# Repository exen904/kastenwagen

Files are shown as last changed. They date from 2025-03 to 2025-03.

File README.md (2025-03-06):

# Kastenwagen 1840 Chunky ISO RP2040

Kastenwagen 1840

Kastenwagen 1840 is a 40% keyboard with a mini-numpad and dedicated arrows.  The main alpha block is 13.75u long, allowing for more dedicated punctuation keys (or non-English letters) to be paired with common Minivan-like mod keys.

Kastenwagen 48 is a similar keyboard that replaces the mini-numpad with a small macro column.

For more information, join the [NoPunIn10Key Discord](https://discord.gg/sku2Y6w).

## RP2040 PCB Port
The PCB in this branch was ported for the use of a RP2040 Community Edition MCU, no Elite-C support! As the pinout of the Elite-C and the RP2040 community footprint is not exactly the same, one of the status LEDs was not working when using such an MCU. For that case, I switched the KiCad files to use a 0xCB Helios as base and changed some of the routing for the new pinout. All status LEDs are now confirmed working.

## Credit

* Keyboard Maintainer: [Alex Ronke](https://nopunin10did.com/), also known as [NoPunIn10Did](https://github.com/NoPunIn10Did)
* Hardware Supported: Kastenwagen 1840 (2021 June)
* Hardware Availability: Currently by request only

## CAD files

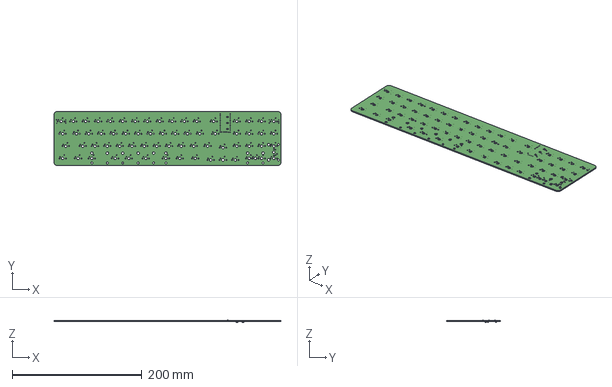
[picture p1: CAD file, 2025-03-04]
kastenwagen-1840-chunky/kastenwagen-1840-chunky.step
350.5 x 83.5 x 3.25 mm

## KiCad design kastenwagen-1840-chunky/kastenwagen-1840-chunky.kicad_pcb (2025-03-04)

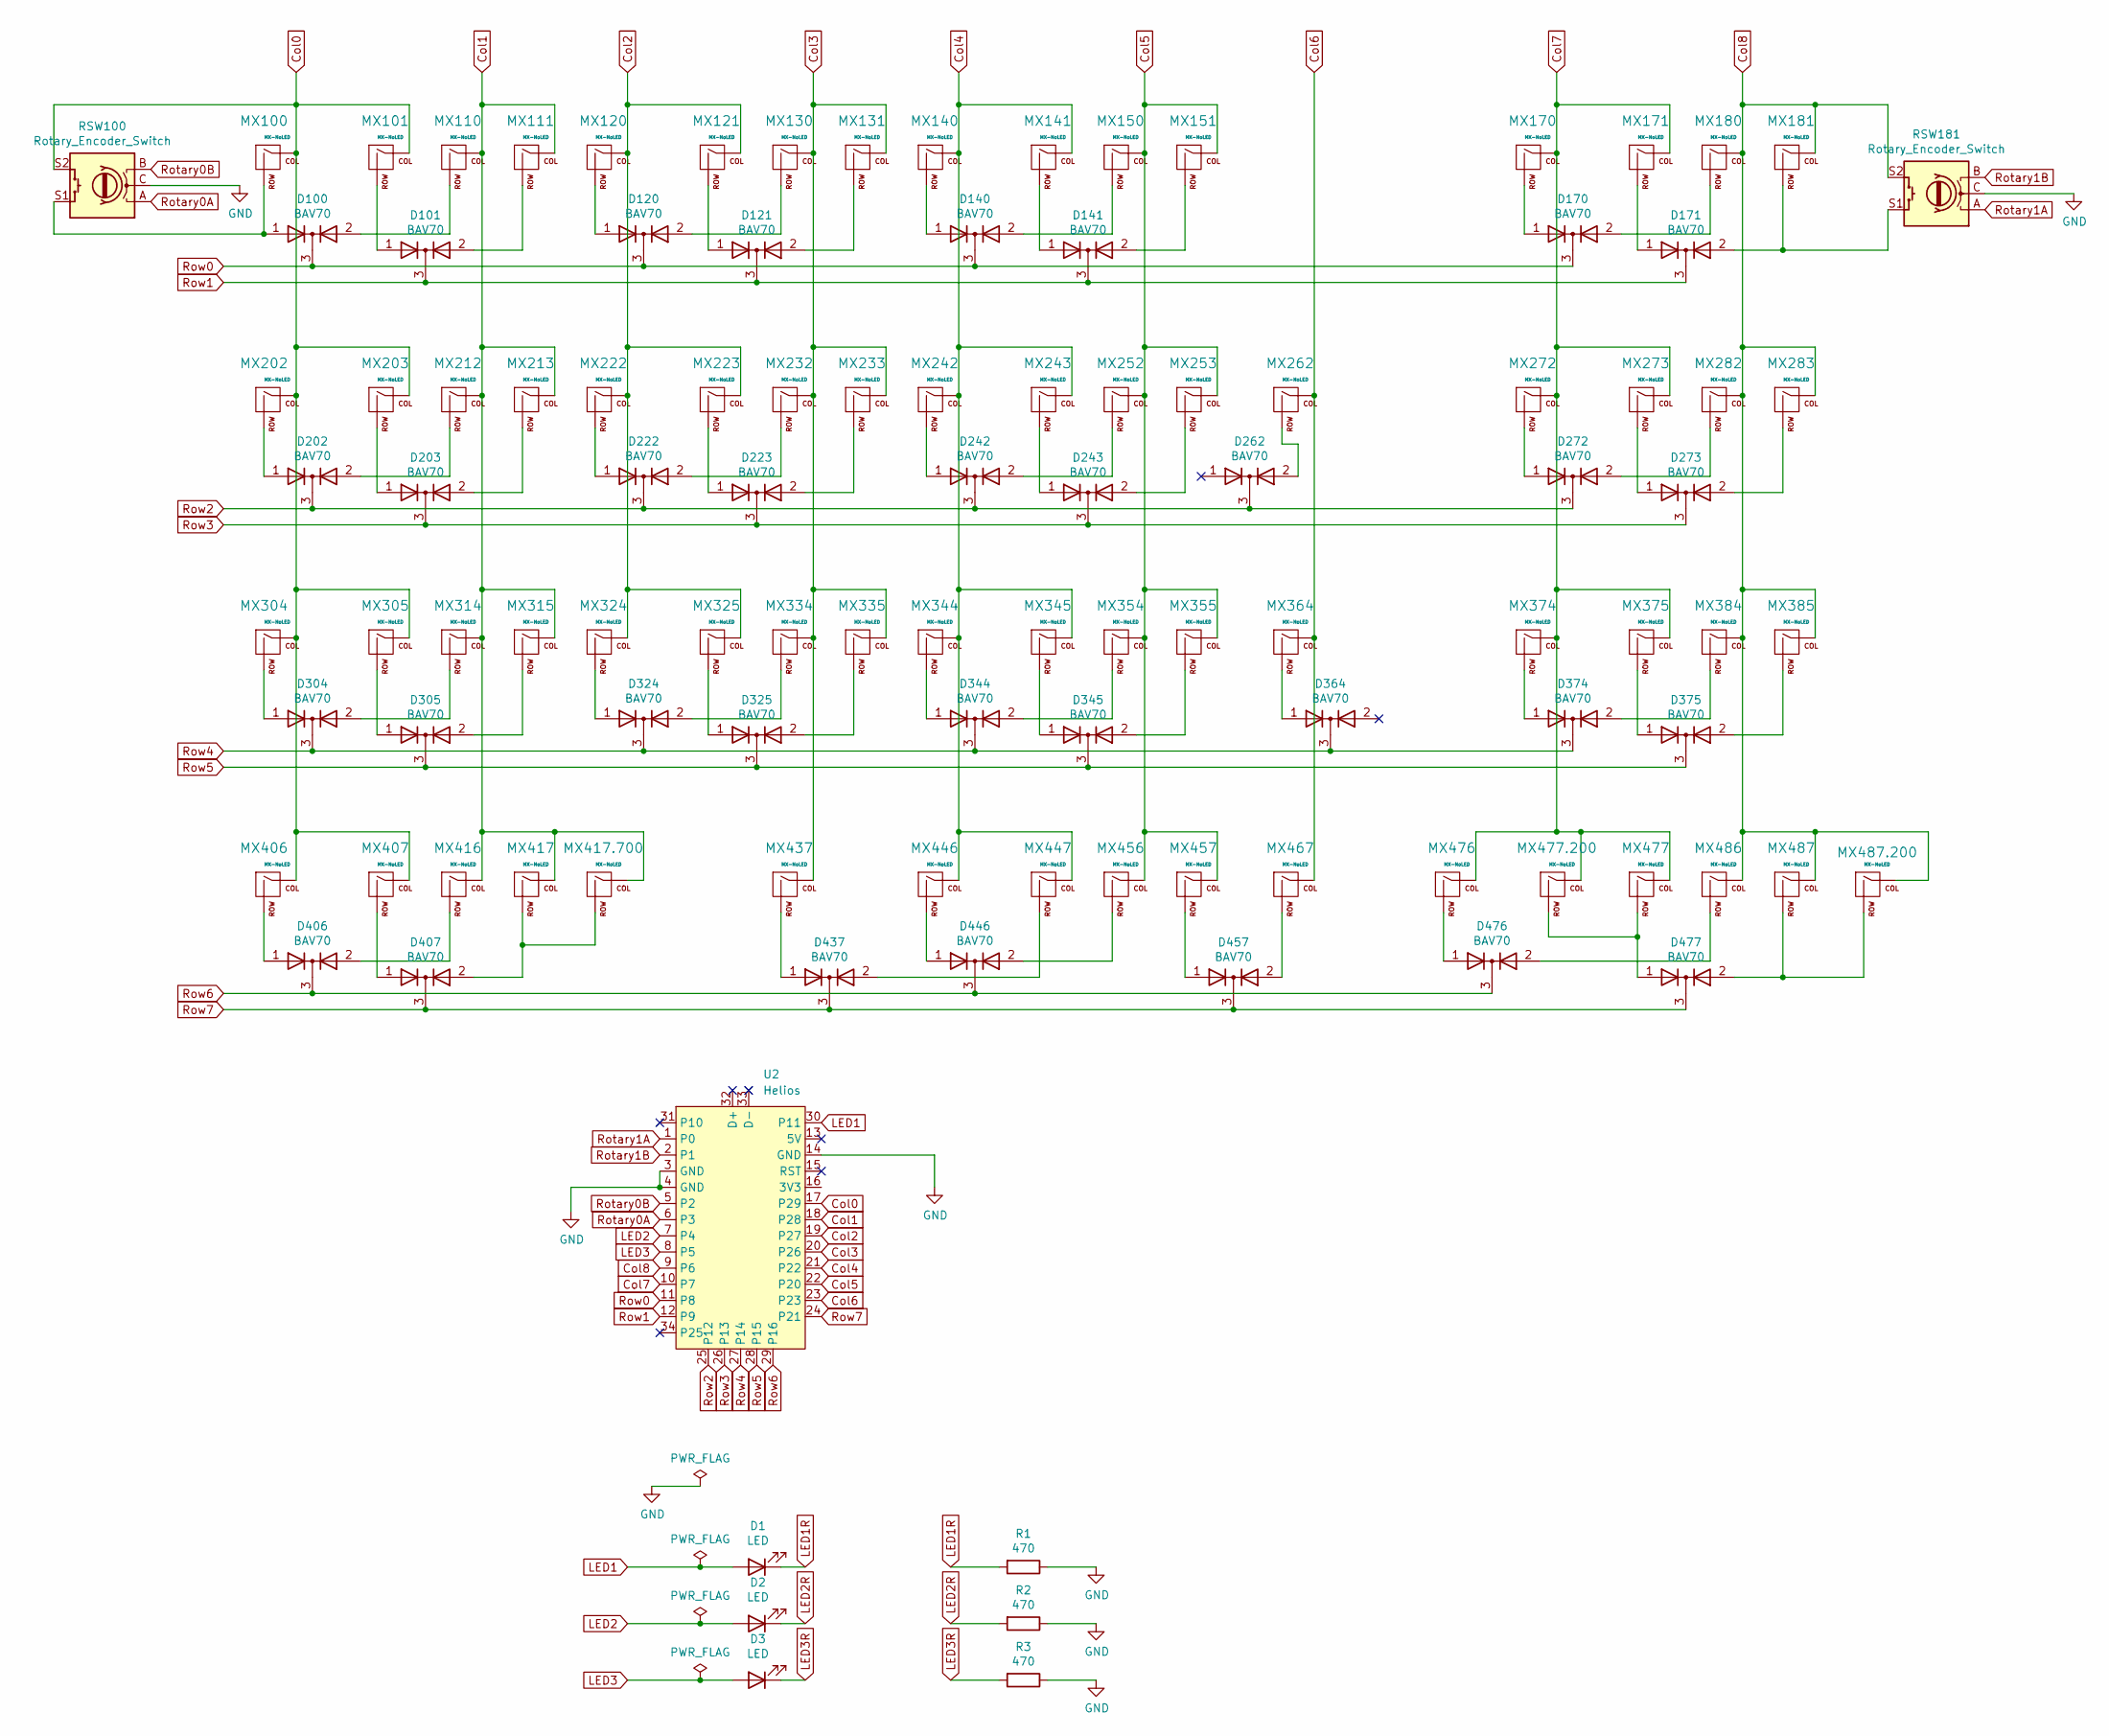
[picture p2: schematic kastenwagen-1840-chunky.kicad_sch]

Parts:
D1, D2, D3: LED; LED_1206_3216Metric_Pad1.42x1.75mm_HandSolder
D100, D101, D120, D121, D140, D141, D170, D171, D202, D203, D222, D223, D242, D243, D262, D272, D273, D304, D305, D324, D325, D344, D345, D364, D374, D375, D406, D407, D437, D446, D457, D476, D477: BAV70; SOT-23_Handsoldering
MX100, MX101, MX110, MX111, MX120, MX121, MX130, MX131, MX140, MX141, MX150, MX151, MX170, MX171, MX180, MX181, MX203, MX212, MX213, MX222, MX223, MX232, MX233, MX242, MX243, MX252, MX253, MX272, MX273, MX282, MX283, MX305, MX314, MX315, MX324, MX325, MX334, MX335, MX344, MX345, MX354, MX364, MX374, MX375, MX384, MX385, MX416, MX446, MX457, MX467, MX476, MX477, MX486, MX487: MX-NoLED; MXOnly-1U-NoLED
MX202, MX355, MX406, MX407, MX447, MX456: MX-NoLED; MXOnly-1.25U-NoLED
MX262: MX-NoLED; MXOnly-ISO-ROTATED-NoLED-NoStabs
MX304: MX-NoLED; MXOnly-1.75U-NoLED
MX417: MX-NoLED; MXOnly-2.75U-ReversedStabilizers-NoLED
MX417.700: MX-NoLED; MXOnly-7U-ReversedStabilizers-NoLED
MX437: MX-NoLED; MXOnly-2.25U-ReversedStabilizers-NoLED
MX477.200: MX-NoLED; MXOnly-2U-ReversedStabilizers-NoLED
MX487.200: MX-NoLED; MXOnly-2U-NoLED
R1, R2, R3: 470; R_0805
RSW100, RSW181: Rotary_Encoder_Switch; RotaryEncoder_EC11-no-legs
U2: Helios; Helios_AH_USBup

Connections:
Col0: MX100.1 (COL), MX101.1 (COL), MX202.1 (COL), MX203.1 (COL), MX304.1 (COL), MX305.1 (COL), MX406.1 (COL), MX407.1 (COL), RSW100.S2, U2.17 (P29)
Col1: MX110.1 (COL), MX111.1 (COL), MX212.1 (COL), MX213.1 (COL), MX314.1 (COL), MX315.1 (COL), MX416.1 (COL), MX417.1 (COL), MX417.700.1 (COL), U2.18 (P28)
Col2: MX120.1 (COL), MX121.1 (COL), MX222.1 (COL), MX223.1 (COL), MX324.1 (COL), MX325.1 (COL), U2.19 (P27)
Col3: MX130.1 (COL), MX131.1 (COL), MX232.1 (COL), MX233.1 (COL), MX334.1 (COL), MX335.1 (COL), MX437.1 (COL), U2.20 (P26)
Col4: MX140.1 (COL), MX141.1 (COL), MX242.1 (COL), MX243.1 (COL), MX344.1 (COL), MX345.1 (COL), MX446.1 (COL), MX447.1 (COL), U2.21 (P22)
Col5: MX150.1 (COL), MX151.1 (COL), MX252.1 (COL), MX253.1 (COL), MX354.1 (COL), MX355.1 (COL), MX456.1 (COL), MX457.1 (COL), U2.22 (P20)
Col6: MX262.1 (COL), MX364.1 (COL), MX467.1 (COL), U2.23
Col7: MX170.1 (COL), MX171.1 (COL), MX272.1 (COL), MX273.1 (COL), MX374.1 (COL), MX375.1 (COL), MX476.1 (COL), MX477.1 (COL), MX477.200.1 (COL), U2.10 (P7)
Col8: MX180.1 (COL), MX181.1 (COL), MX282.1 (COL), MX283.1 (COL), MX384.1 (COL), MX385.1 (COL), MX486.1 (COL), MX487.1 (COL), MX487.200.1 (COL), RSW181.S2, U2.9 (P6)
GND: R1.1, R2.1, R3.1, RSW100.C, RSW181.C, U2.3 (GND), U2.4 (GND), U2.14 (GND)
LED1: D1.2 (A), U2.30 (P11)
LED1R: D1.1 (K), R1.2
LED2: D2.2 (A), U2.7 (P4)
LED2R: D2.1 (K), R2.2
LED3: D3.2 (A), U2.8 (P5)
LED3R: D3.1 (K), R3.2
unnamed: D100.1 (A), MX100.2 (ROW), RSW100.S1
unnamed: D101.1 (A), MX101.2 (ROW)
unnamed: D100.2 (A), MX110.2 (ROW)
unnamed: D101.2 (A), MX111.2 (ROW)
unnamed: D120.1 (A), MX120.2 (ROW)
unnamed: D121.1 (A), MX121.2 (ROW)
unnamed: D120.2 (A), MX130.2 (ROW)
unnamed: D121.2 (A), MX131.2 (ROW)
unnamed: D140.1 (A), MX140.2 (ROW)
unnamed: D141.1 (A), MX141.2 (ROW)
unnamed: D140.2 (A), MX150.2 (ROW)
unnamed: D141.2 (A), MX151.2 (ROW)
unnamed: D170.1 (A), MX170.2 (ROW)
unnamed: D171.1 (A), MX171.2 (ROW)
unnamed: D170.2 (A), MX180.2 (ROW)
unnamed: D171.2 (A), MX181.2 (ROW), RSW181.S1
unnamed: D202.1 (A), MX202.2 (ROW)
unnamed: D203.1 (A), MX203.2 (ROW)
unnamed: D202.2 (A), MX212.2 (ROW)
unnamed: D203.2 (A), MX213.2 (ROW)
unnamed: D222.1 (A), MX222.2 (ROW)
unnamed: D223.1 (A), MX223.2 (ROW)
unnamed: D222.2 (A), MX232.2 (ROW)
unnamed: D223.2 (A), MX233.2 (ROW)
unnamed: D242.1 (A), MX242.2 (ROW)
unnamed: D243.1 (A), MX243.2 (ROW)
unnamed: D242.2 (A), MX252.2 (ROW)
unnamed: D243.2 (A), MX253.2 (ROW)
unnamed: D262.2 (A), MX262.2 (ROW)
unnamed: D272.1 (A), MX272.2 (ROW)
unnamed: D273.1 (A), MX273.2 (ROW)
unnamed: D272.2 (A), MX282.2 (ROW)
unnamed: D273.2 (A), MX283.2 (ROW)
unnamed: D304.1 (A), MX304.2 (ROW)
unnamed: D305.1 (A), MX305.2 (ROW)
unnamed: D304.2 (A), MX314.2 (ROW)
unnamed: D305.2 (A), MX315.2 (ROW)
unnamed: D324.1 (A), MX324.2 (ROW)
unnamed: D325.1 (A), MX325.2 (ROW)
unnamed: D324.2 (A), MX334.2 (ROW)
unnamed: D325.2 (A), MX335.2 (ROW)
unnamed: D344.1 (A), MX344.2 (ROW)
unnamed: D345.1 (A), MX345.2 (ROW)
unnamed: D344.2 (A), MX354.2 (ROW)
unnamed: D345.2 (A), MX355.2 (ROW)
unnamed: D364.1 (A), MX364.2 (ROW)
unnamed: D374.1 (A), MX374.2 (ROW)
unnamed: D375.1 (A), MX375.2 (ROW)
unnamed: D374.2 (A), MX384.2 (ROW)
unnamed: D375.2 (A), MX385.2 (ROW)
unnamed: D406.1 (A), MX406.2 (ROW)
unnamed: D407.1 (A), MX407.2 (ROW)
unnamed: D406.2 (A), MX416.2 (ROW)
unnamed: D407.2 (A), MX417.2 (ROW), MX417.700.2 (ROW)
unnamed: D437.1 (A), MX437.2 (ROW)
unnamed: D446.1 (A), MX446.2 (ROW)
unnamed: D437.2 (A), MX447.2 (ROW)
unnamed: D446.2 (A), MX456.2 (ROW)
unnamed: D457.1 (A), MX457.2 (ROW)
unnamed: D457.2 (A), MX467.2 (ROW)
unnamed: D476.1 (A), MX476.2 (ROW)
unnamed: D477.1 (A), MX477.2 (ROW), MX477.200.2 (ROW)
unnamed: D476.2 (A), MX486.2 (ROW)
unnamed: D477.2 (A), MX487.2 (ROW), MX487.200.2 (ROW)
Rotary0A: RSW100.A, U2.6 (P3)
Rotary0B: RSW100.B, U2.5 (P2)
Rotary1A: RSW181.A, U2.1 (P0)
Rotary1B: RSW181.B, U2.2 (P1)
Row0: D100.3 (K), D120.3 (K), D140.3 (K), D170.3 (K), U2.11 (P8)
Row1: D101.3 (K), D121.3 (K), D141.3 (K), D171.3 (K), U2.12 (P9)
Row2: D202.3 (K), D222.3 (K), D242.3 (K), D262.3 (K), D272.3 (K), U2.25 (P12)
Row3: D203.3 (K), D223.3 (K), D243.3 (K), D273.3 (K), U2.26 (P13)
Row4: D304.3 (K), D324.3 (K), D344.3 (K), D364.3 (K), D374.3 (K), U2.27 (P14)
Row5: D305.3 (K), D325.3 (K), D345.3 (K), D375.3 (K), U2.28 (P15)
Row6: D406.3 (K), D446.3 (K), D476.3 (K), U2.29 (P16)
Row7: D407.3 (K), D437.3 (K), D457.3 (K), D477.3 (K), U2.24 (P21)

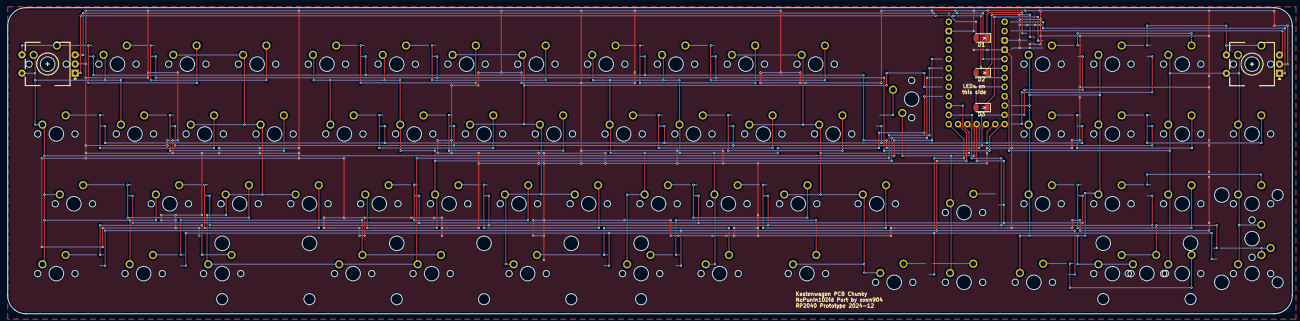
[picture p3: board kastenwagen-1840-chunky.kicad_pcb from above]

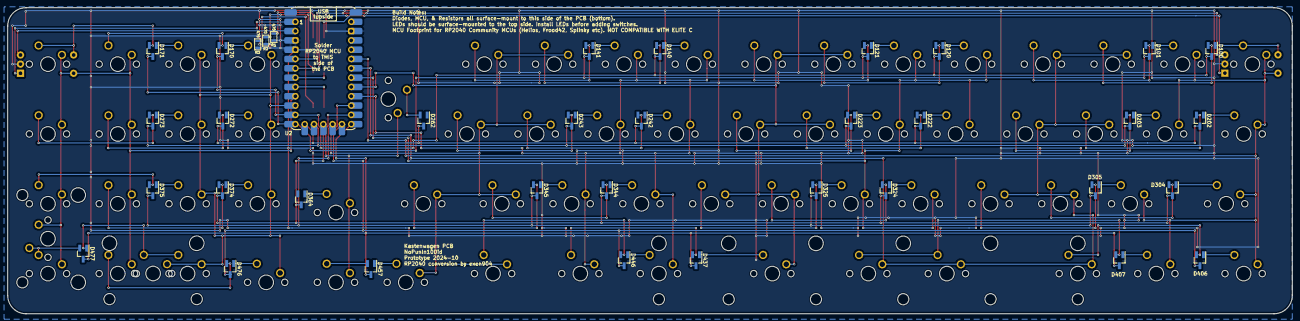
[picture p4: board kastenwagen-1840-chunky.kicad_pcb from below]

Board: 2 copper layers, 350.5 x 83.5 mm, 109 parts (37 on the bottom side), 92 nets.

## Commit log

2025-03-04 RP2040 port for ISO Kastenwagen
    [kastenwagen-1840-chunky-B_Cu.gbl, kastenwagen-1840-chunky-B_Mask.gbs, kastenwagen-1840-chunky-B_Silkscreen.gbo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]
2025-03-04 Silkscreen update
    [kastenwagen-1840-chunky.kicad_pcb]
2026-11-03 updated Silkscreen and readme, only Helios will fully function with this PCB port
